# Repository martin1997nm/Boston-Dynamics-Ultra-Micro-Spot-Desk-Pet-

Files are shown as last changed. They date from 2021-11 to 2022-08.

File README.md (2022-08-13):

# Boston-Dynamics-Ultra-Micro-Spot-Desk-Pet-

This project started as a passion for robots and I wanted to make a little desk pet that I can program easily.
The moves are really limited due to the 4 servo setup and the development is really slow because I don't really have much free time,
so if you have suggestions or want to take part in the development feel free to edit the code.

## Version 1
### You will need

- ESP 8266 Wemos D1 Mini
- Passive buzzer
- Microswitch
- Eachine E58 Drone battery (it has an integrated BMS and I had 5 lying around)
- 4 pieces of 9gram servos(I used metal geared but you can use plastic geared)
- Soldering iron, wires, standard 1.54 pin headers
- Screwdriver

## Version 2
### You will need

- MH-ET LIVE D1 Mini ESP32
- Passive buzzer
- Microswitch
- IR Sensor
- MPU 9250 IMU
- Battery is not selected yet
- 8 pieces of 9gram servos(I used metal geared but you can use plastic geared)
- Soldering iron, wires, standard 1.54 pin headers, 2 mm welding rod for joint connections
- Screwdriver

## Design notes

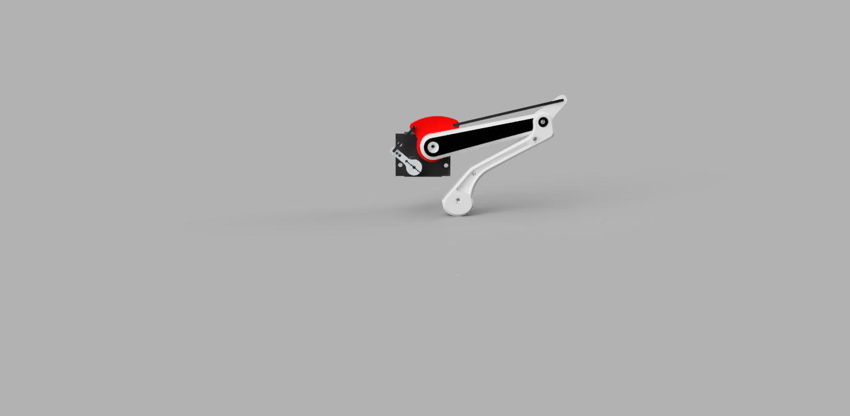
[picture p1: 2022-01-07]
V2/Render/robot_dog_2021-Nov-23_01-56-40AM-000_CustomizedView16645071227.png

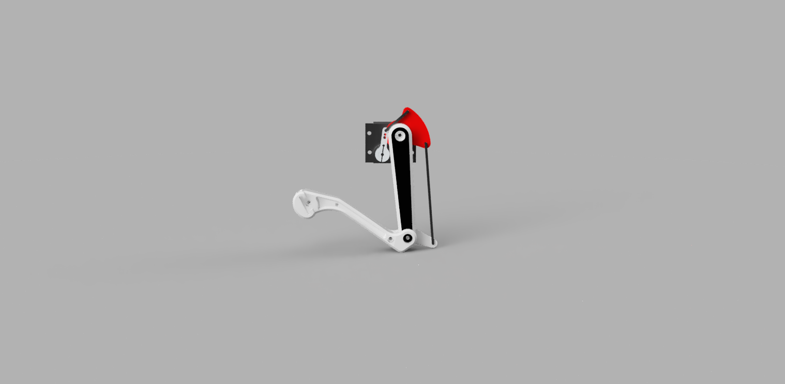
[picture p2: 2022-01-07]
V2/Render/robot_dog_2021-Nov-23_01-57-54AM-000_CustomizedView16645071227.png

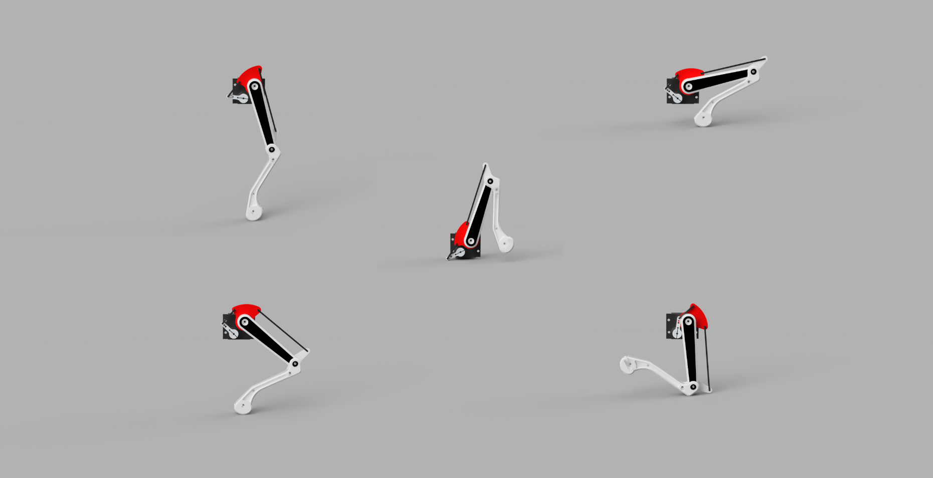
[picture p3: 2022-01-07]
V2/Render/Névtelen.png

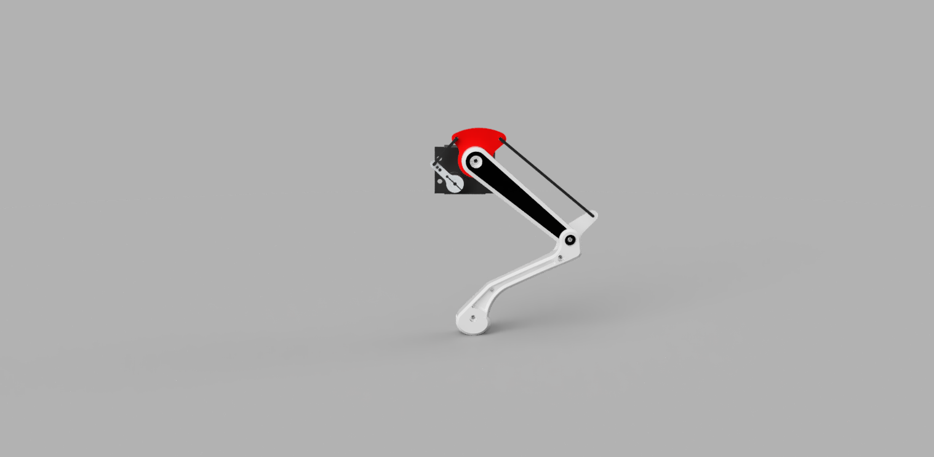
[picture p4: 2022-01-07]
V2/Render/robot_dog_2021-Nov-23_01-57-08AM-000_CustomizedView16645071227.png

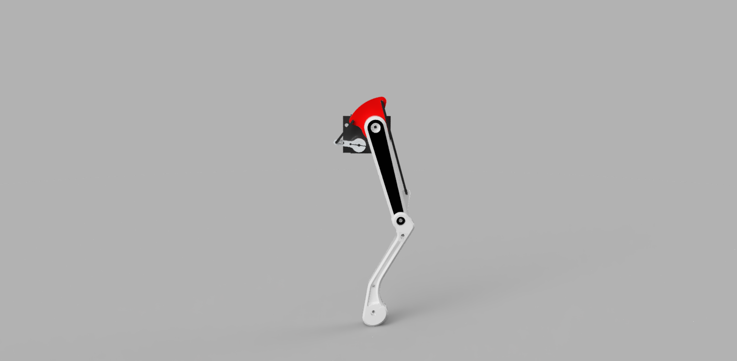
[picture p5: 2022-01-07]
V2/Render/robot_dog_2021-Nov-23_01-55-28AM-000_CustomizedView16645071227.png

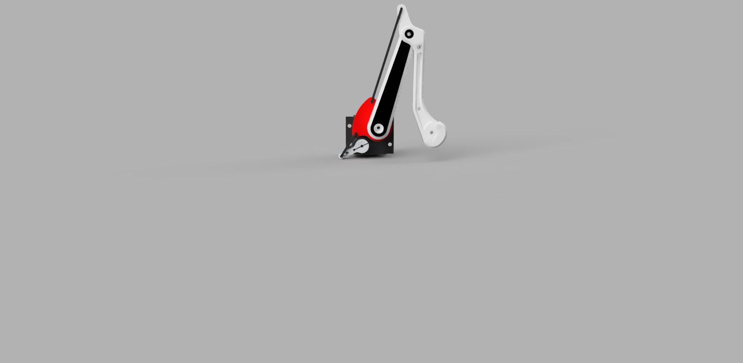
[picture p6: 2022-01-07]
V2/Render/robot_dog_2021-Nov-23_01-58-36AM-000_CustomizedView16645071227.png

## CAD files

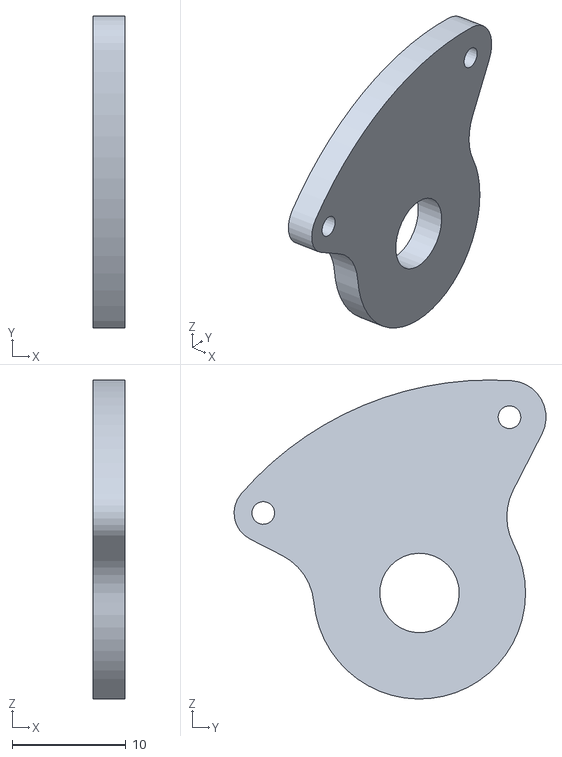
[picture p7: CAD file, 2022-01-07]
V2/Modell/left_joint.stl
2.79 x 27.5 x 28.1

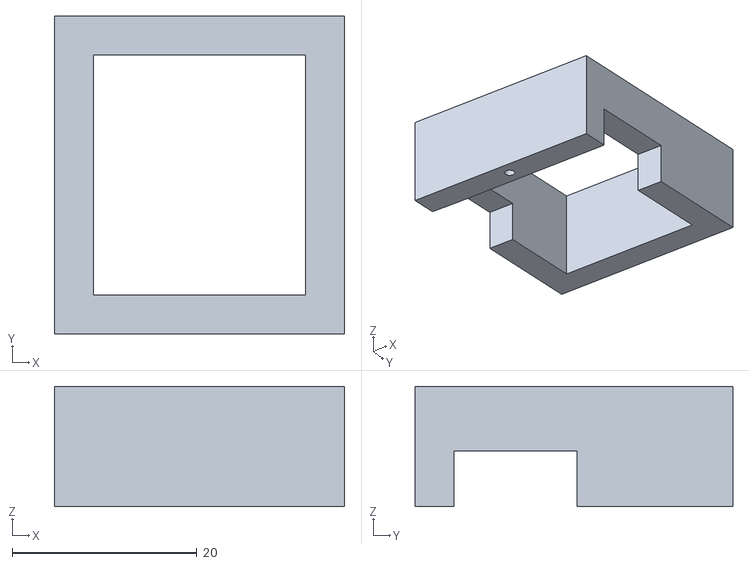
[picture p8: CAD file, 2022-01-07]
V2/Modell/servo_test_stand v2.stl
31.4 x 34.4 x 13.0

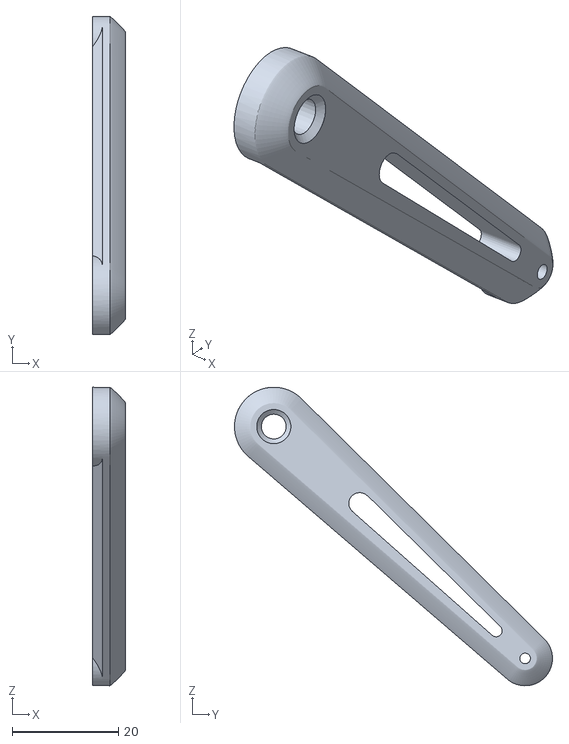
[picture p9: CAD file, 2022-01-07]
V2/Modell/upper_left_leg.stl
6.30 x 59.9 x 56.2

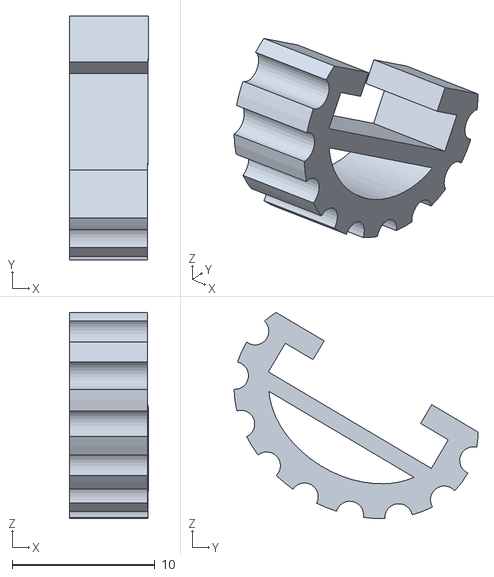
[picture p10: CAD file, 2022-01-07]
V2/Modell/paw.stl
5.53 x 17.1 x 14.5

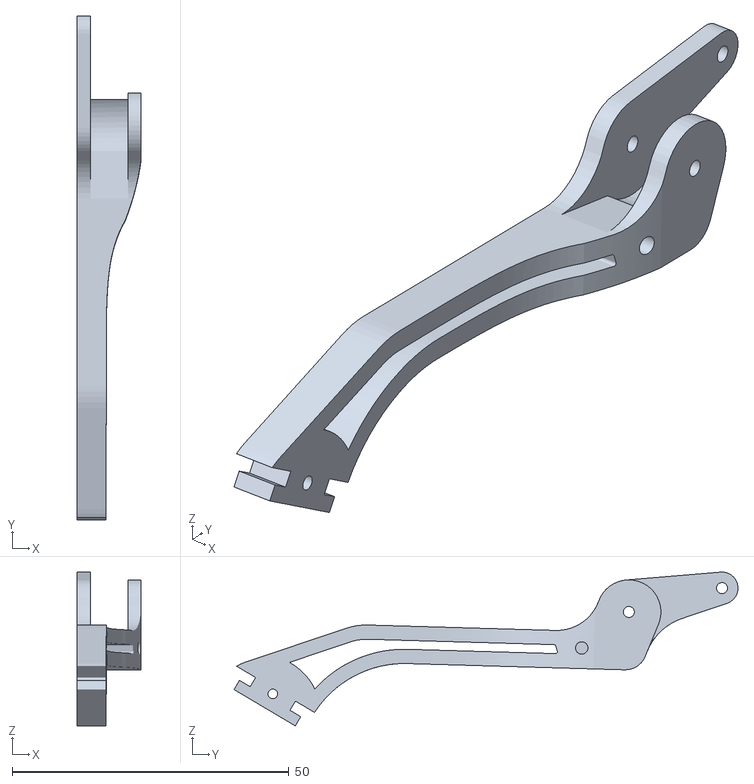
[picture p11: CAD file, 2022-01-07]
V2/Modell/lower_left_leg.stl
11.6 x 91.1 x 27.8

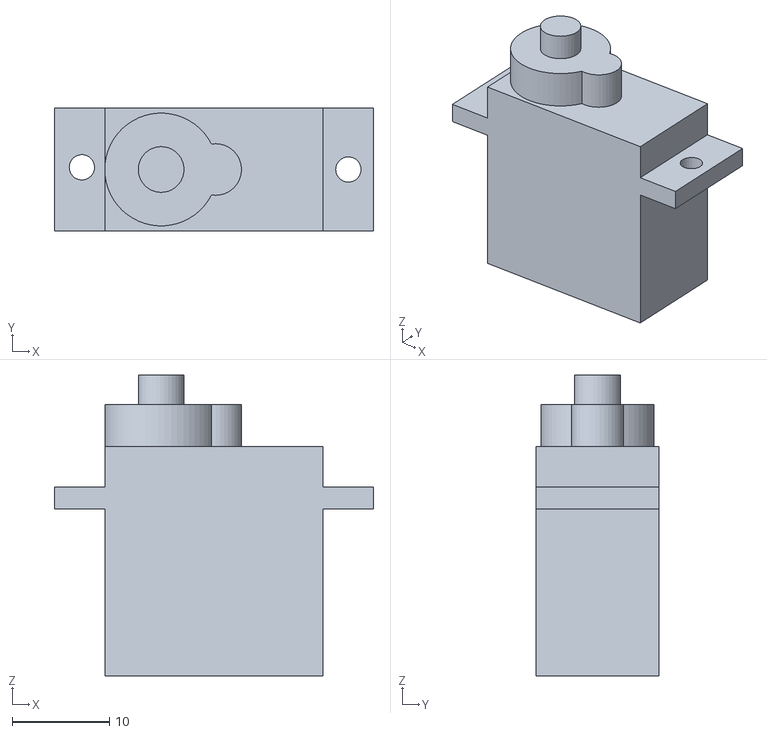
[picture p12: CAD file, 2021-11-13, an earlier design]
V1/Modells/servo.stl
32.8 x 12.6 x 30.9

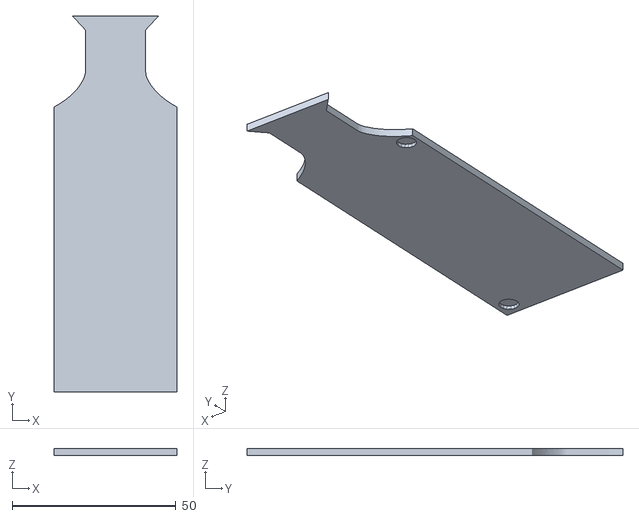
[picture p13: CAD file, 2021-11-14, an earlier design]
V1/WeBoots/protos/spotURDF_description/meshes/lid_1.stl
37.5 x 114.7 x 2.00

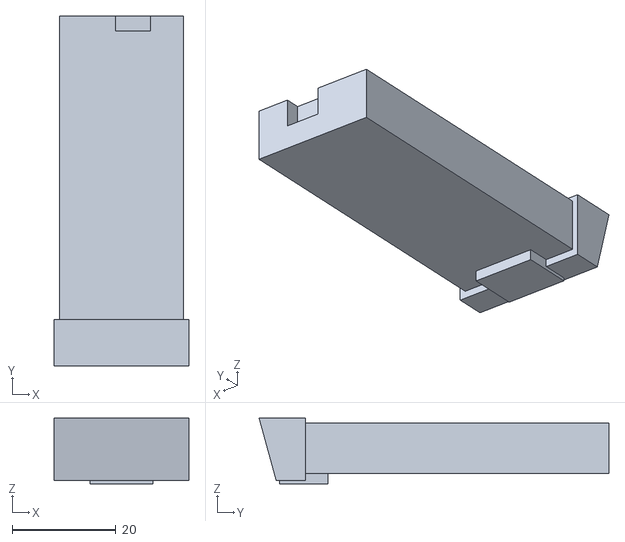
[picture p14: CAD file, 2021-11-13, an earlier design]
V1/Modells/battery.stl
26.0 x 67.4 x 12.6

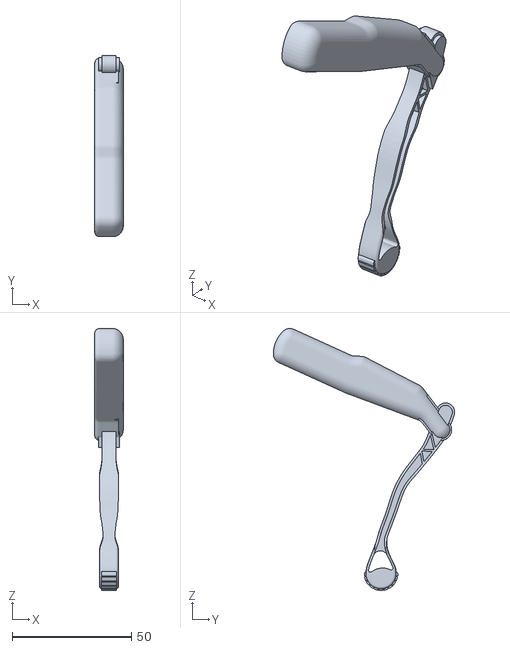
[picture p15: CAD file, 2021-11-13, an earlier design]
V1/Modells/spot_leg_left.stl
12.0 x 76.1 x 109.8

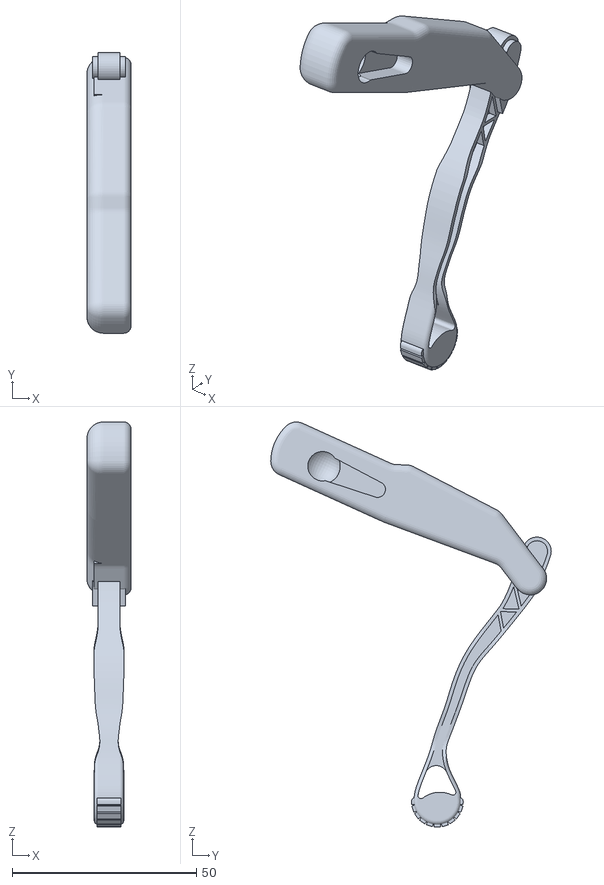
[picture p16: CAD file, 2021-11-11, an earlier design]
V1/Modells/spot_leg.stl
12.0 x 76.1 x 109.8

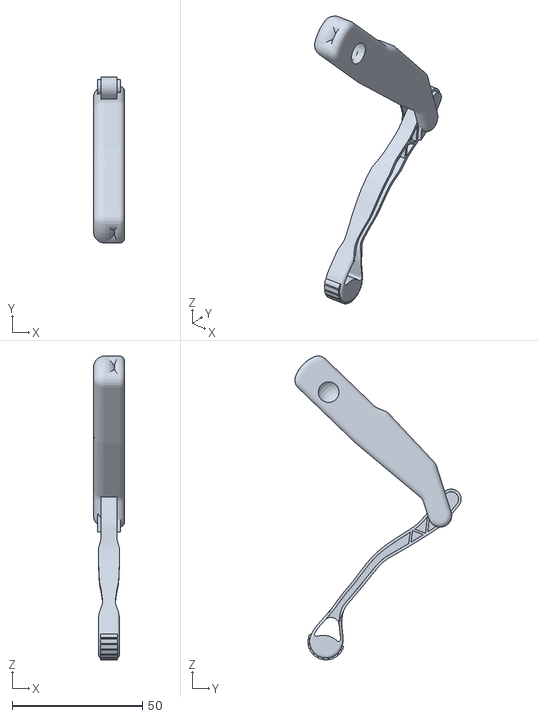
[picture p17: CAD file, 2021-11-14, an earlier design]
V1/WeBoots/protos/spotURDF_description/meshes/rr_leg_1.stl
12.0 x 64.0 x 116.9

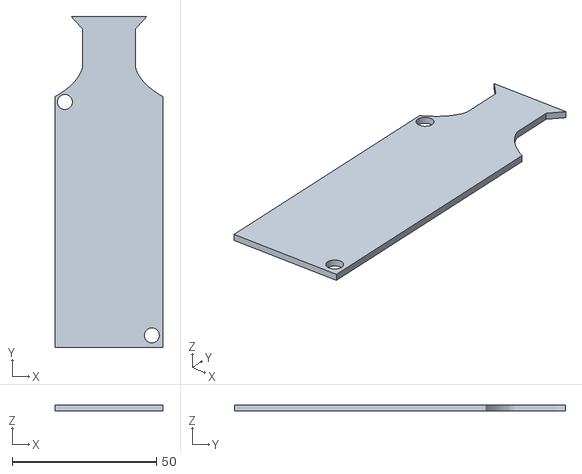
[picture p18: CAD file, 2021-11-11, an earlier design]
V1/Modells/lid.stl
37.5 x 114.7 x 2.00

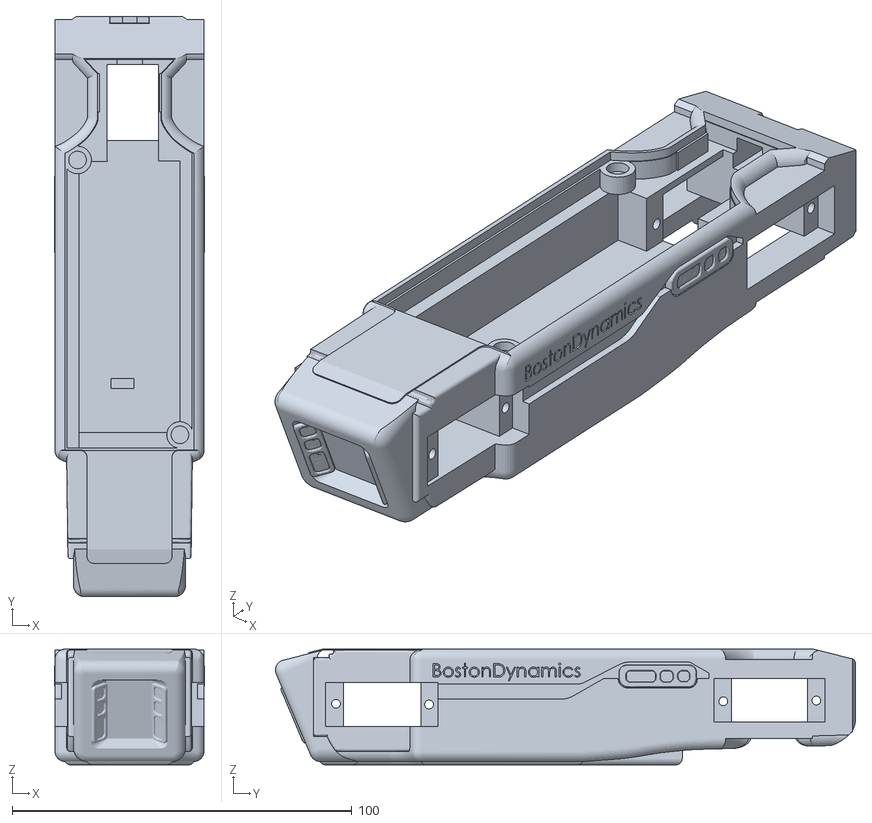
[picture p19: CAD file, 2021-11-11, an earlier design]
V1/Modells/spot_body.stl
44.1 x 170.7 x 34.1

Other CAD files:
V1/WeBoots/protos/spotURDF_description/meshes/servo__2__1.stl
V1/WeBoots/protos/spotURDF_description/meshes/servo_1.stl
V1/WeBoots/protos/spotURDF_description/meshes/fr_leg_1.stl
V1/WeBoots/protos/spotURDF_description/meshes/fl_leg__1__1.stl
V1/WeBoots/protos/spotURDF_description/meshes/base_link.stl
V1/WeBoots/protos/spotURDF_description/meshes/battery_1.stl
V1/WeBoots/protos/spotURDF_description/meshes/fl_leg_1.stl
V1/WeBoots/protos/spotURDF_description/meshes/servo__1__1.stl
V1/WeBoots/protos/spotURDF_description/meshes/servo__3__1.stl

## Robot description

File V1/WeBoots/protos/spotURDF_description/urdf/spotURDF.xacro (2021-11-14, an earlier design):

<?xml version="1.0" ?>
<robot name="spotURDF" xmlns:xacro="http://www.ros.org/wiki/xacro">

<xacro:include filename="$(find spotURDF_description)/urdf/materials.xacro" />
<xacro:include filename="$(find spotURDF_description)/urdf/spotURDF.trans" />
<xacro:include filename="$(find spotURDF_description)/urdf/spotURDF.gazebo" />
<link name="base_link">
  <inertial>
    <origin rpy="0 0 0" xyz="0.05971230943588049 0.1915410353054319 0.10379183049192559"/>
    <mass value="0.15593839458053116"/>
    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
  </inertial>
  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
</link>

<link name="servo_1">
  <inertial>
    <origin rpy="0 0 0" xyz="-0.004038544658970675 0.013204850014472719 -0.00022426075196999018"/>
    <mass value="0.010362264661810883"/>
    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
  </inertial>
  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
</link>

<link name="servo__3__1">
  <inertial>
    <origin rpy="0 0 0" xyz="-0.004038365236444921 0.013205437003384363 -0.00022426047629711676"/>
    <mass value="0.010362264661810883"/>
    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
  </inertial>
  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
</link>

<link name="servo__1__1">
  <inertial>
    <origin rpy="0 0 0" xyz="0.004038365889253284 0.013204850014472663 0.0002247877672378884"/>
    <mass value="0.010362264661810883"/>
    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
  </inertial>
  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
</link>

<link name="servo__2__1">
  <inertial>
    <origin rpy="0 0 0" xyz="0.004038365889253395 0.013205437003384474 0.00022478804291048426"/>
    <mass value="0.010362264661810883"/>
    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
  </inertial>
  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
</link>

<link name="fr_leg_1">
  <inertial>
    <origin rpy="0 0 0" xyz="-0.005828531513050319 0.014049939833651048 -0.027769452214174692"/>
    <mass value="0.02306397378886889"/>
    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
  </inertial>
  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
</link>

<link name="fl_leg_1">
  <inertial>
    <origin rpy="0 0 0" xyz="0.005828352048753149 0.013044620216436043 -0.0282560129079764"/>
    <mass value="0.02306393986938087"/>
    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
  </inertial>
  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
</link>

<link name="fl_leg__1__1">
  <inertial>
    <origin rpy="0 0 0" xyz="0.005828531471279166 0.014739240692406896 -0.02741050389011923"/>
    <mass value="0.02306393986938087"/>
    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
  </inertial>
  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
</link>

<link name="rr_leg_1">
  <inertial>
    <origin rpy="0 0 0" xyz="-0.005828531513050374 0.013172479995305464 -0.028196535474165382"/>
    <mass value="0.02306397378886889"/>
    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
  </inertial>
  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
</link>

<link name="lid_1">
  <inertial>
    <origin rpy="0 0 0" xyz="0.0152823789173697 -0.03282391466918336 0.0010028365291432084"/>
    <mass value="0.01247391983033411"/>
    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
  </inertial>
  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
</link>

<joint name="Rigid1" type="fixed">
  <origin rpy="0 0 0" xyz="0.07692 0.129093 0.105972"/>
  <parent link="base_link"/>
  <child link="servo_1"/>
</joint>

<joint name="Rigid2" type="fixed">
  <origin rpy="0 0 0" xyz="0.07696 0.24309 0.106709"/>
  <parent link="base_link"/>
  <child link="servo__3__1"/>
</joint>

<joint name="Rigid3" type="fixed">
  <origin rpy="0 0 0" xyz="0.04282 0.129093 0.105972"/>
  <parent link="base_link"/>
  <child link="servo__1__1"/>
</joint>

<joint name="Rigid4" type="fixed">
  <origin rpy="0 0 0" xyz="0.04272 0.24309 0.106709"/>
  <parent link="base_link"/>
  <child link="servo__2__1"/>
</joint>

<joint name="Rev5" type="revolute">
  <origin rpy="0 0 0" xyz="-0.01078 0.008137 0.000224"/>
  <parent link="servo__1__1"/>
  <child link="fr_leg_1"/>
  <axis xyz="-1.0 -0.0 0.0"/>
  <limit effort="100" lower="-1.745329" upper="2.007129" velocity="100"/>
</joint>

<joint name="Rev6" type="revolute">
  <origin rpy="0 0 0" xyz="0.01078 0.008137 -0.000224"/>
  <parent link="servo_1"/>
  <child link="fl_leg_1"/>
  <axis xyz="1.0 -0.0 -0.0"/>
  <limit effort="100" lower="-2.007129" upper="1.745329" velocity="100"/>
</joint>

<joint name="Rev7" type="revolute">
  <origin rpy="0 0 0" xyz="0.01078 0.008137 -0.000224"/>
  <parent link="servo__3__1"/>
  <child link="fl_leg__1__1"/>
  <axis xyz="1.0 -0.0 0.0"/>
  <limit effort="100" lower="-1.745329" upper="2.268928" velocity="100"/>
</joint>

<joint name="Rev8" type="revolute">
  <origin rpy="0 0 0" xyz="-0.01078 0.008137 0.000224"/>
  <parent link="servo__2__1"/>
  <child link="rr_leg_1"/>
  <axis xyz="-1.0 -0.0 -0.0"/>
  <limit effort="100" lower="-2.268928" upper="1.745329" velocity="100"/>
</joint>

<joint name="Rigid9" type="fixed">
  <origin rpy="0 0 0" xyz="0.04454 0.23975 0.119878"/>
  <parent link="base_link"/>
  <child link="lid_1"/>
</joint>

</robot>

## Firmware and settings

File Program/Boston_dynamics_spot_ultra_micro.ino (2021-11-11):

#include <ESP8266WiFi.h>
#include "uMQTTBroker.h"
#include <Servo.h>

char ssid[] = "Boston Dynamics Spot";     // your network SSID (name)
char pass[] = "Spot1234"; // your network password
bool WiFiAP = true;      // Do yo want the ESP as AP?

String TOP;
String DAT;
String TOPIC = "/sit";
String TOPIC1 = "/stand";
String TOPIC2 = "/walk";
String TOPIC3 = "/left";
String TOPIC4 = "/right";
String TOPIC5 = "/rr";     //rr
String TOPIC6 = "/rl";     //rl
String TOPIC7 = "/fl";     //fl
String TOPIC8 = "/fr";     //fr
String TOPIC9 = "/lay"; 
String TOPIC10 = "/pit"; 
String TOPIC11 = "/getup"; 

const unsigned char Passive_buzzer = 13;
Servo rear_right;
Servo rear_left;
Servo front_left;
Servo front_right;

class myMQTTBroker: public uMQTTBroker
{
public:
    virtual bool onConnect(IPAddress addr, uint16_t client_count) {
      Serial.println(addr.toString()+" connected");
      return true;
    }
    
    virtual bool onAuth(String username, String password) {
      Serial.println("Username/Password: "+username+"/"+password);
      return true;
    }
    
    virtual void onData(String topic, const char *data, uint32_t length) {
      char data_str[length+1];
      os_memcpy(data_str, data, length);
      data_str[length] = '\0';
      Serial.println("received topic '"+topic+"' with data '"+(String)data_str+"'");
      TOP =topic;
      DAT = (String)data_str;
      
    }
};

myMQTTBroker myBroker;

void startWiFiAP()
{
  WiFi.mode(WIFI_AP);
  
WiFi.softAP(ssid,pass);
  Serial.println("AP started");
  Serial.println("IP address: " + WiFi.softAPIP().toString());
}

void startWiFiClient()
{
  WiFi.hostname("Bite Indicator");
  WiFi.mode(WIFI_STA);
 
  WiFi.begin(ssid, pass);
  
  while (WiFi.status() != WL_CONNECTED) {
    delay(500);
    Serial.print(".");
  }
  Serial.println("");
  
  Serial.println("WiFi connected");
  Serial.println("IP address: " + WiFi.localIP().toString());
}

void setup() {  
  delay(2000);
 pinMode (Passive_buzzer,OUTPUT) ;
 digitalWrite(Passive_buzzer,HIGH);

 Serial.begin(115200);
  rear_right.attach(0);
  rear_left.attach(2);
  front_left.attach(4);
  front_right.attach(5);

   // Start WiFi
  if (WiFiAP)
    startWiFiAP();
  else
    startWiFiClient();

  // Start the broker
  Serial.println("Starting MQTT broker");
  Serial.println(pass);
  myBroker.init();
  myBroker.subscribe("#");
  
  stand();
   tone(13, 329.63, 300);
  delay(100);
  tone(13, 311.13, 300);
  delay(100);
  tone(13, 329.63, 300);
  delay(100);
  tone(13,311.13, 300);
  delay(100);
  tone(13, 329.63, 300);
  delay(100);
  tone(13, 246.94, 300);
  delay(100);
  tone(13, 293.66,300);
  delay(100);
  tone(13, 261.63,300);
  delay(150);
  tone(13, 220, 900);
  digitalWrite(Passive_buzzer,HIGH);
}

void loop() {
   if (TOP == TOPIC) {if(DAT == "0"){DAT="1";sit();}}
   if (TOP == TOPIC1){if(DAT == "0"){DAT="1";stand();}}
   if (TOP == TOPIC2){if(DAT == "0"){walk();}}
   if (TOP == TOPIC3){if(DAT == "0"){left();}}
   if (TOP == TOPIC4){if(DAT == "0"){right();}}
   if (TOP == TOPIC5) {rear_right.write(DAT.toInt());}
   if (TOP == TOPIC6) {rear_left.write(DAT.toInt());}
   if (TOP == TOPIC7) {front_left.write(DAT.toInt());}
   if (TOP == TOPIC8) {front_right.write(DAT.toInt());}
   if (TOP == TOPIC9){if(DAT == "0"){DAT="1";lay();}}
   if (TOP == TOPIC10){if(DAT == "0"){DAT="1";pit();}}
   if (TOP == TOPIC11){if(DAT == "0"){DAT="1";getup();}}
    delay(300);
}

void getup(){
 tone(Passive_buzzer, 659) ;
 front_left.write(90);   front_right.write(90);  
 rear_left.write(180);   rear_right.write(0);
 delay(200);
 front_left.write(90);   front_right.write(90);  
 rear_left.write(90);   rear_right.write(90);
 digitalWrite(Passive_buzzer,HIGH);
}

void stand (){
 tone(Passive_buzzer, 659) ;
 front_left.write(90);   front_right.write(90);  
 rear_left.write(90);   rear_right.write(90);
 delay(400);
 digitalWrite(Passive_buzzer,HIGH);
}

void sit (){ 
 tone(Passive_buzzer, 587) ;
 front_left.write(30);   front_right.write(150);  
 rear_left.write(30);   rear_right.write(150);
 delay(400);
 digitalWrite(Passive_buzzer,HIGH);
}

void lay (){ 
 tone(Passive_buzzer, 587) ;
 front_left.write(0);   front_right.write(180);  
 rear_left.write(180);   rear_right.write(0);
 delay(400);
 digitalWrite(Passive_buzzer,HIGH);
}

void pit (){ 
 tone(Passive_buzzer, 587) ;
 front_left.write(90);   front_right.write(90);  
 rear_left.write(180);   rear_right.write(0);
 delay(200);
 front_left.write(90);   front_right.write(90);  
 rear_left.write(150);   rear_right.write(0);
  delay(200);
 front_left.write(90);   front_right.write(90);  
 rear_left.write(180);   rear_right.write(30);
 delay(200);
 front_left.write(90);   front_right.write(90);  
 rear_left.write(150);   rear_right.write(0);
  delay(200);
 front_left.write(90);   front_right.write(90);  
 rear_left.write(180);   rear_right.write(30);
 digitalWrite(Passive_buzzer,HIGH);
}

void walk (){
 tone(Passive_buzzer, 523) ; //DO note 523 Hz
 delay (200);
 digitalWrite(Passive_buzzer,HIGH);
 front_left.write(90);  front_right.write(90);  
 rear_left.write(90);  rear_right.write(90);
 delay (200);
 front_left.write(50);
 delay (200);
 rear_right.write(110);
 delay (200);
 front_right.write(130);
 delay (200);
 rear_left.write(60);
}

void right (){
 delay(150);
 //fl rl 130
 //fr rr 60
 //stand
 front_right.write(120);
 delay(150);

 rear_right.write(120);
 delay(150);

 front_left.write(70);
 delay(150);

 rear_left.write(70);
 delay(150);



 stand();
}

void left (){
 delay (100);
 //fl 50, delay 100, rl 50, delay 100
 //fr 120, delay 100, rr 120, delay 100
 //stand

 front_left.write(60);
 delay(150);

 rear_left.write(60);
 delay(150);

 front_right.write(110);
 delay(150);

 rear_right.write(110);
 delay(150);

 stand();
}

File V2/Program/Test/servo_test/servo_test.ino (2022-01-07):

#include "MPU9250.h"
#include <ESP32Servo.h>

//MPU
MPU9250 IMU(Wire,0x68);
int status;

//Buzzer
const int PIN =4;
hw_timer_t* timer = NULL;
bool value = true;
int frequency =50; // 20 to 20000

//Servo
#define S1 26 
#define S2 18 
#define S3 19 
#define S4 23 
#define S5 27
#define S6 25
#define S7 32 
#define S8 12 

Servo servoMotor1;
Servo servoMotor2;
Servo servoMotor3;
Servo servoMotor4;
Servo servoMotor5;
Servo servoMotor6;
Servo servoMotor7;
Servo servoMotor8;

void IRAM_ATTR onTimer() {
  value = !value;
  digitalWrite(PIN, value); 
}

void setup() {
  Serial.begin(115200);
  
  //MPU
  while(!Serial) {}

  // start communication with IMU 
  status = IMU.begin();
  if (status < 0) {
    Serial.println("IMU initialization unsuccessful");
    Serial.println("Check IMU wiring or try cycling power");
    Serial.print("Status: ");
    Serial.println(status);
    while(1) {}
  }
  
  //Buzzer
  pinMode(PIN, OUTPUT);// sets the digital pin as output
  digitalWrite(PIN,HIGH);
  setupTimer();
  
  //Servo
  servoMotor1.attach(S1);
  servoMotor2.attach(S2);
  servoMotor3.attach(S3);
  servoMotor4.attach(S4);
  servoMotor5.attach(S5);
  servoMotor6.attach(S6);
  servoMotor7.attach(S7);
  servoMotor8.attach(S8);  
}
void setupTimer() {
    // Use 1st timer of 4  - 1 tick take 1/(80MHZ/80) = 1us so we set divider 80 and count up 
    timer = timerBegin(0, 80, true);//div 80
    timerAttachInterrupt(timer, &onTimer, true);
}

void setFrequency(long frequencyHz){
    timerAlarmDisable(timer);
    timerAlarmWrite(timer, 1000000l / frequencyHz, true);
    timerAlarmEnable(timer);
}

void tone(long frequencyHz, long durationMs){
    setFrequency(frequencyHz);
    delay(durationMs);
}

void loop() {
  imuGetData();
  servoControll();
  delay(300);
  tone(frequency,1000);
  delay(1000);
  digitalWrite(PIN,HIGH);
}

void imuGetData(){
IMU.readSensor();
  // display the data
  Serial.print(IMU.getAccelX_mss(),6);
  Serial.print("\t");
  Serial.print(IMU.getAccelY_mss(),6);
  Serial.print("\t");
  Serial.print(IMU.getAccelZ_mss(),6);
  Serial.print("\t");
  Serial.print(IMU.getGyroX_rads(),6);
  Serial.print("\t");
  Serial.print(IMU.getGyroY_rads(),6);
  Serial.print("\t");
  Serial.print(IMU.getGyroZ_rads(),6);
  Serial.print("\t");
  Serial.print(IMU.getMagX_uT(),6);
  Serial.print("\t");
  Serial.print(IMU.getMagY_uT(),6);
  Serial.print("\t");
  Serial.print(IMU.getMagZ_uT(),6);
  Serial.print("\t");
  Serial.println(IMU.getTemperature_C(),6);
  delay(100);
}

void servoControll(){
   for (int pos = 0; pos <= 180; pos += 10) {
    servoMotor1.write(pos);
    servoMotor2.write(pos);
    servoMotor3.write(pos);
    servoMotor4.write(pos);
    servoMotor5.write(pos);
    servoMotor6.write(pos);
    servoMotor7.write(pos);
    servoMotor8.write(pos);
    delay(15); 
  }

  for (int pos = 180; pos >= 0; pos -= 10) {
    servoMotor1.write(pos);
    servoMotor2.write(pos);
    servoMotor3.write(pos);
    servoMotor4.write(pos);
    servoMotor5.write(pos);
    servoMotor6.write(pos);
    servoMotor7.write(pos);
    servoMotor8.write(pos);
    delay(15); 
  }
}

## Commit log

2021-11-11 modells added
    [lid.stl, spot_body.stl, spot_leg.stl]
2021-11-11 refactored servo variable names
2021-11-11 potencial fix for left/right turn
    [Boston_dynamics_spot_ultra_micro.ino]
2021-11-11 added write to servo calls
2021-11-11 Tuned servo states while turning
2021-11-12 Servo speed controll testing for rear right leg
2021-11-12 reworked base logic of servo turning
    [Boston_dynamics_spot_ultra_micro.ino]
2021-11-12 made separate setServo functions per servo
2021-11-13 Integrated servo speed controll to all leg TOPIC-s
2021-11-13 Reworked walking method without standby
    now it has no lagg due to not changing topics while walking
    [Boston_dynamics_spot_ultra_micro.ino]
2021-11-13 Webots 3D modelling asetts created
    [spot_leg_left.stl]
2021-11-13 servo and battery modell added
    [battery.stl, servo.stl]
2021-11-13 added a blender file with the dog assembled
2021-11-13 moved leg origins to joints
2021-11-14 URDF modell created
    [base_link.stl, battery_1.stl, controller.yaml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]
2021-11-14 added spot URDF to proto conversion
2021-11-14 Still trying to make webots work
    [base_link.stl, battery_1.stl, fl_leg_1.stl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]
2021-11-18 Trying to make webots some what useable (still)
    [base_link.stl, battery_1.stl, controller.yaml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]
2021-11-18 webots model leg mass adjustment
2022-01-07 Refactoring the project due to making of the second version
    [Spot.kicad_pcb, Spot.sch, base_link.stl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]
2022-01-07 Added modells and wifi test
    [left_joint.stl, lower_left_leg.stl, paw.stl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]
2022-01-10 Invers kinematic and TCP test
2022-03-17 Added android project with mqtt connection base to start off with
    [app_bar_main.xml]
